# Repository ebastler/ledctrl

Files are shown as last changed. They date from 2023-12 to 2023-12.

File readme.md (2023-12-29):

# ledctrl
This project was born with the idea of creating a simple and efficient way of controlling an RGB, one WW/CW and an additional aux stripe from a single smart-home capable controller. Then feature creep happened, and here we are.

The PCB uses a modern and power-efficient RISC-V based ESP32C6 and features a step-down converter to supply the 5V logic, as well as an LDO for the 3.3V logic. The Aux channel has a separate supply input from the other 5 channels, and both supply domains can be used for 12V or 24V stripes, not necessarily the same voltage at the same time. The logic supply is generated from either of the two supply channels, which are ORed together with diodes.

2 inputs for external buttons can be used to directly control the LEDs, or send commands via MQTT. I also added headers for the most common breakout boards for a bunch of different environmental sensors. 

While programming over USB works without issues for ESP32C6, I also added a UART header as a fallback, for debugging or just for use as another GPIO breakout.

### Features:
* Up to 5+1 channels of 12V or 24V LED stripes
* ESP32C6
* USB-C for programming
* Dim onboard LEDs to indicate status of each PWM channel, as well as both input power domains
* WS2812B LED onboard as a status indicator/for devboard use
* Almost all unused GPIOs are available on headers
* Headers for BME280, SCD40 and SGP40 environment sensors
* 2 inputs for pushbuttons/switches

### Software
The board is mainly made for use with [Tasmota](https://github.com/arendst/tasmota), and currently only supported using the `tasmota32c6cdc` firmware, taken off the `13.3.0.1` development branch. Stable versions have not yet added support for this chip. A template that can make use of most features will be published at a later point, once I finalized my firmware setup.

### Pictures
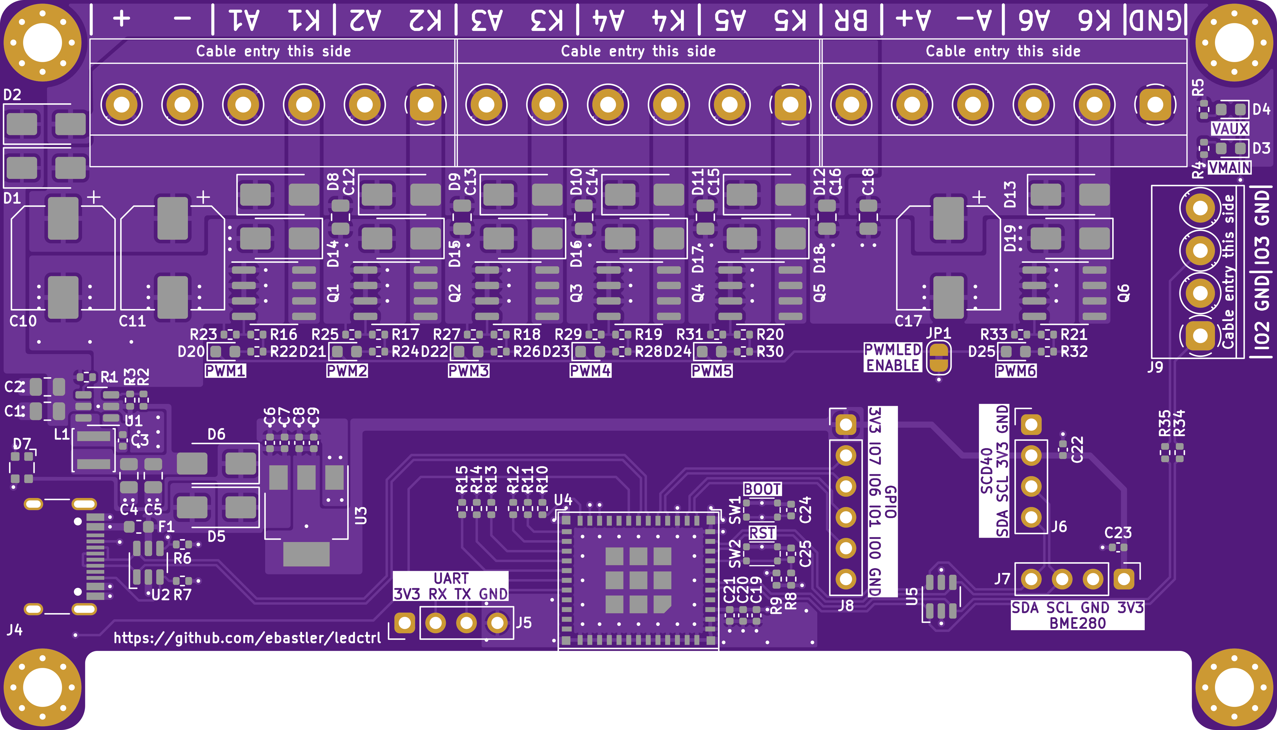
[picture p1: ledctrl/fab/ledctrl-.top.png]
topside


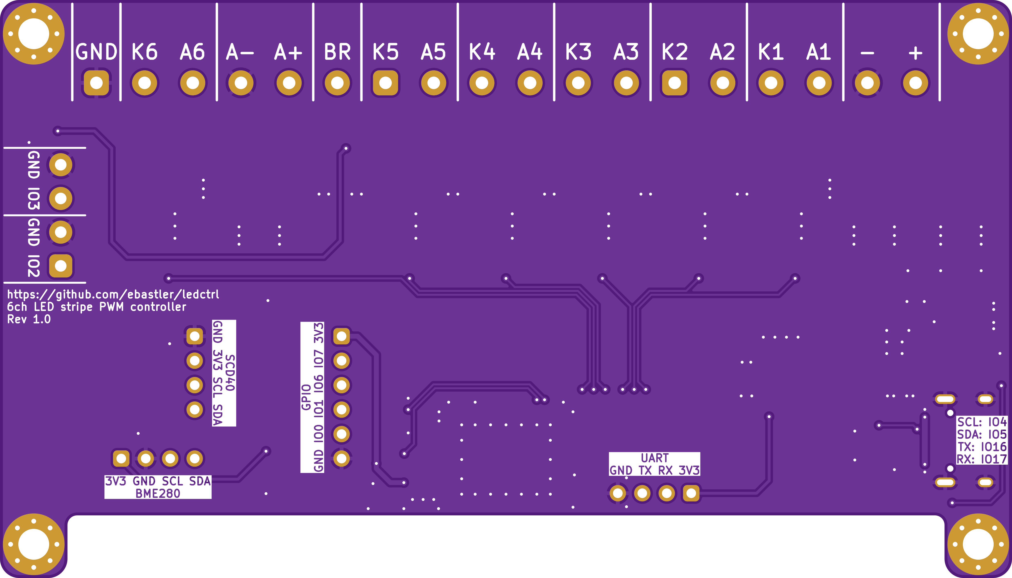
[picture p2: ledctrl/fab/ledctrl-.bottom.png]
botside


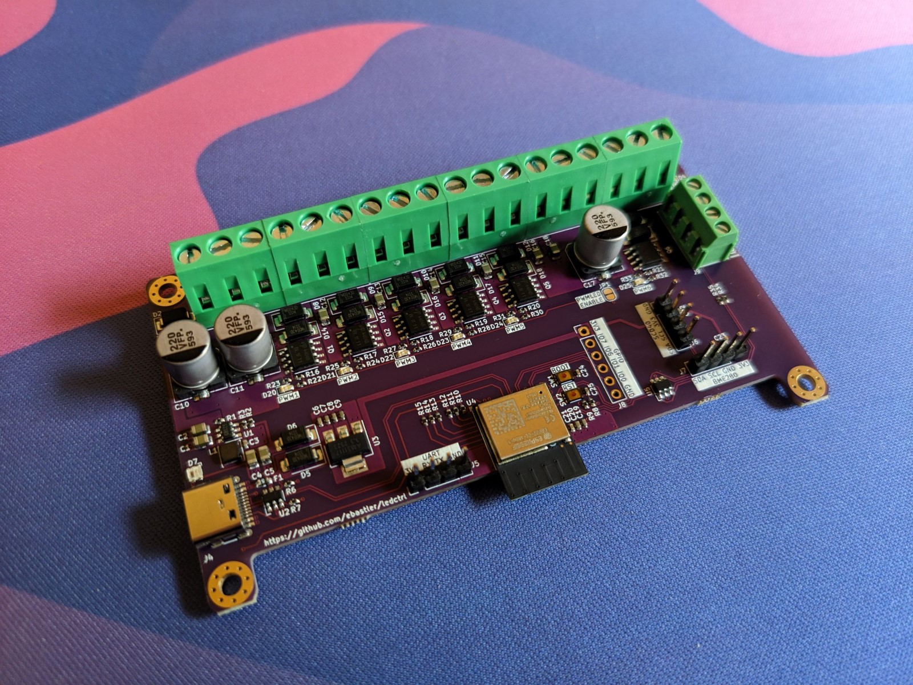
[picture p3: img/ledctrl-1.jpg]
overview of a PCB


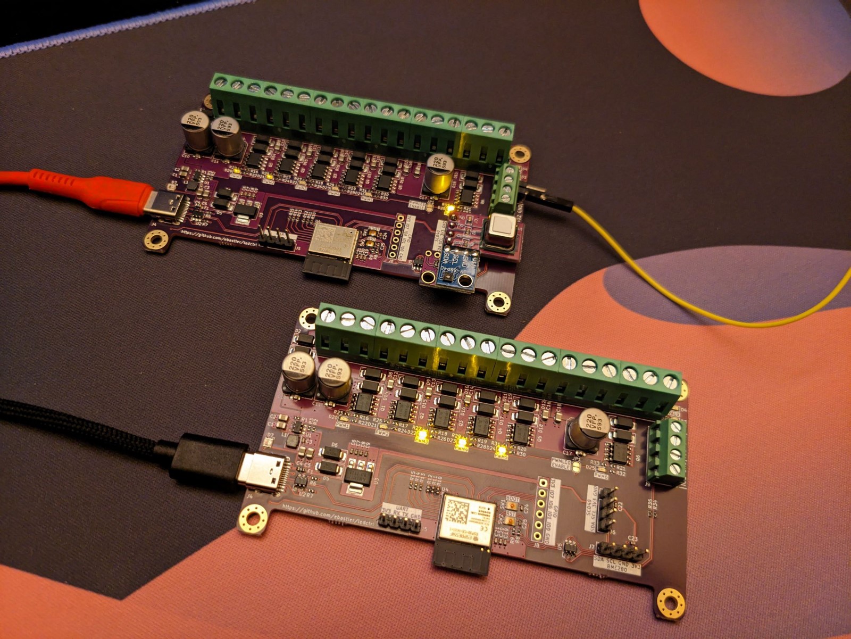
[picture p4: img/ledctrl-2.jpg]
PCBs being tested on a desk


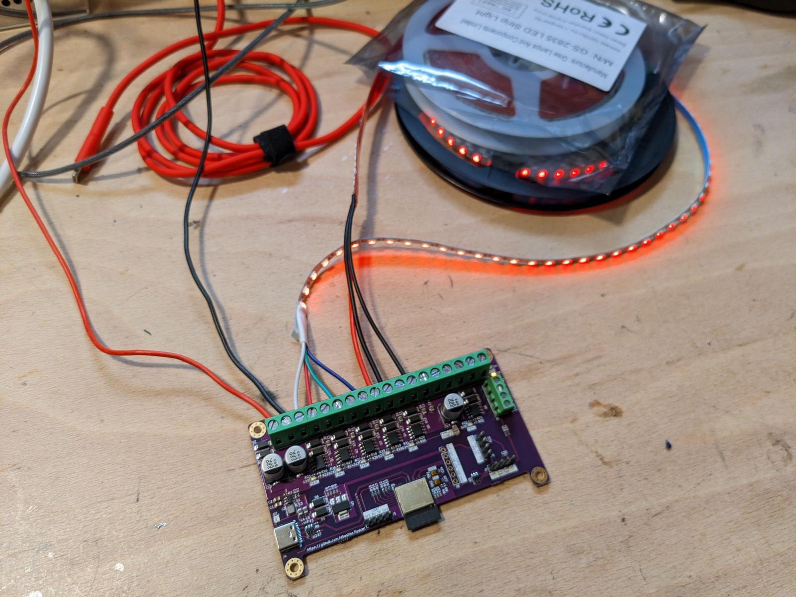
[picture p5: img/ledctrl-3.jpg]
PCB with active LED output


## Thanks
* arendst and the whole community of Tasmota contributors for their excellent firmware
* [MarvFPV](https://github.com/marvfpv) who surprisingly did not get upset about me sending updates of new revisions with minimal changes every other day asking for his opinion

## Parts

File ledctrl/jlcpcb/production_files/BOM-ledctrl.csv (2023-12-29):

Comment | Designator | Footprint | LCSC
BOOT | SW1,SW2 | SW_T1A2QR | C100056
AO4404B | Q1,Q2,Q3,Q4,Q5,Q6 | SOIC-8_3.9x4.9mm_P1.27mm | C115829
HRO M-12 | J4 | USB_C_Receptacle_HRO_TYPE-C-31-M-12 | C165948
0R | R10,R11,R12,R13,R14,R15,R34,R35 | R_0402_1005Metric | C17168
ST1 | J1,J2,J3 | TerminalBlock_Ningbo_Kangnex _WJ128V-5.0-6P_1x06_P5.00mm_Horizontal | C192771
500 mA | F1 | Fuse_0603_1608Metric | C20789
4u7 | C19,C20,C22,C23,C6,C7,C8,C9 | C_0402_1005Metric | C23733
SS14 | D1,D10,D11,D12,D13,D14,D15,D16,D17,D18,D19,D2,D5,D6,D8,D9 | D_SMA | C2480
100 | R16,R17,R18,R19,R20,R21 | R_0402_1005Metric | C25076
10k | R1,R23,R25,R27,R29,R3,R31,R33,R8 | R_0402_1005Metric | C25744
51k | R2,R4,R5 | R_0402_1005Metric | C25794
3k3 | R22,R24,R26,R28,R30,R32,R9 | R_0402_1005Metric | C25890
5k1 | R6,R7 | R_0402_1005Metric | C25905
UART | J5,J6,J7 | PinHeader_1x04_P2.54mm_Vertical | C2691448
EXP2 | J9 | TerminalBlock_DIBO_DB125-3.5-4P-GN-S_1x04_P3.50mm_Horizontal | C2757925
220u | C10,C11,C17 | CP_Elec_8x10 | C278406
TPMP2359DJ | U1 | SOT-23-6 | C2959845
100n | C21,C24,C3 | C_0402_1005Metric | C307331
4u7 | L1 | L_Changjiang_FNR3012S | C528014
1u | C25 | C_0402_1005Metric | C52923
ESP32-C6-MINI-1/U | U4 | ESP32-C6-MINI-1 | C5736265
22u | C1,C12,C13,C14,C15,C16,C18,C2,C4,C5 | C_0805_2012Metric | C6119901
AMS1117-3.3 | U3 | SOT-223-3_TabPin2 | C6186
Y | D20,D21,D22,D23,D24,D25,D3,D4 | LED_0603_1608Metric | C72038
SRV05-4 | U2,U5 | SOT-23-6-routable | C85364
WS2812 | D7 | LED_WS2812_2020 | C965555

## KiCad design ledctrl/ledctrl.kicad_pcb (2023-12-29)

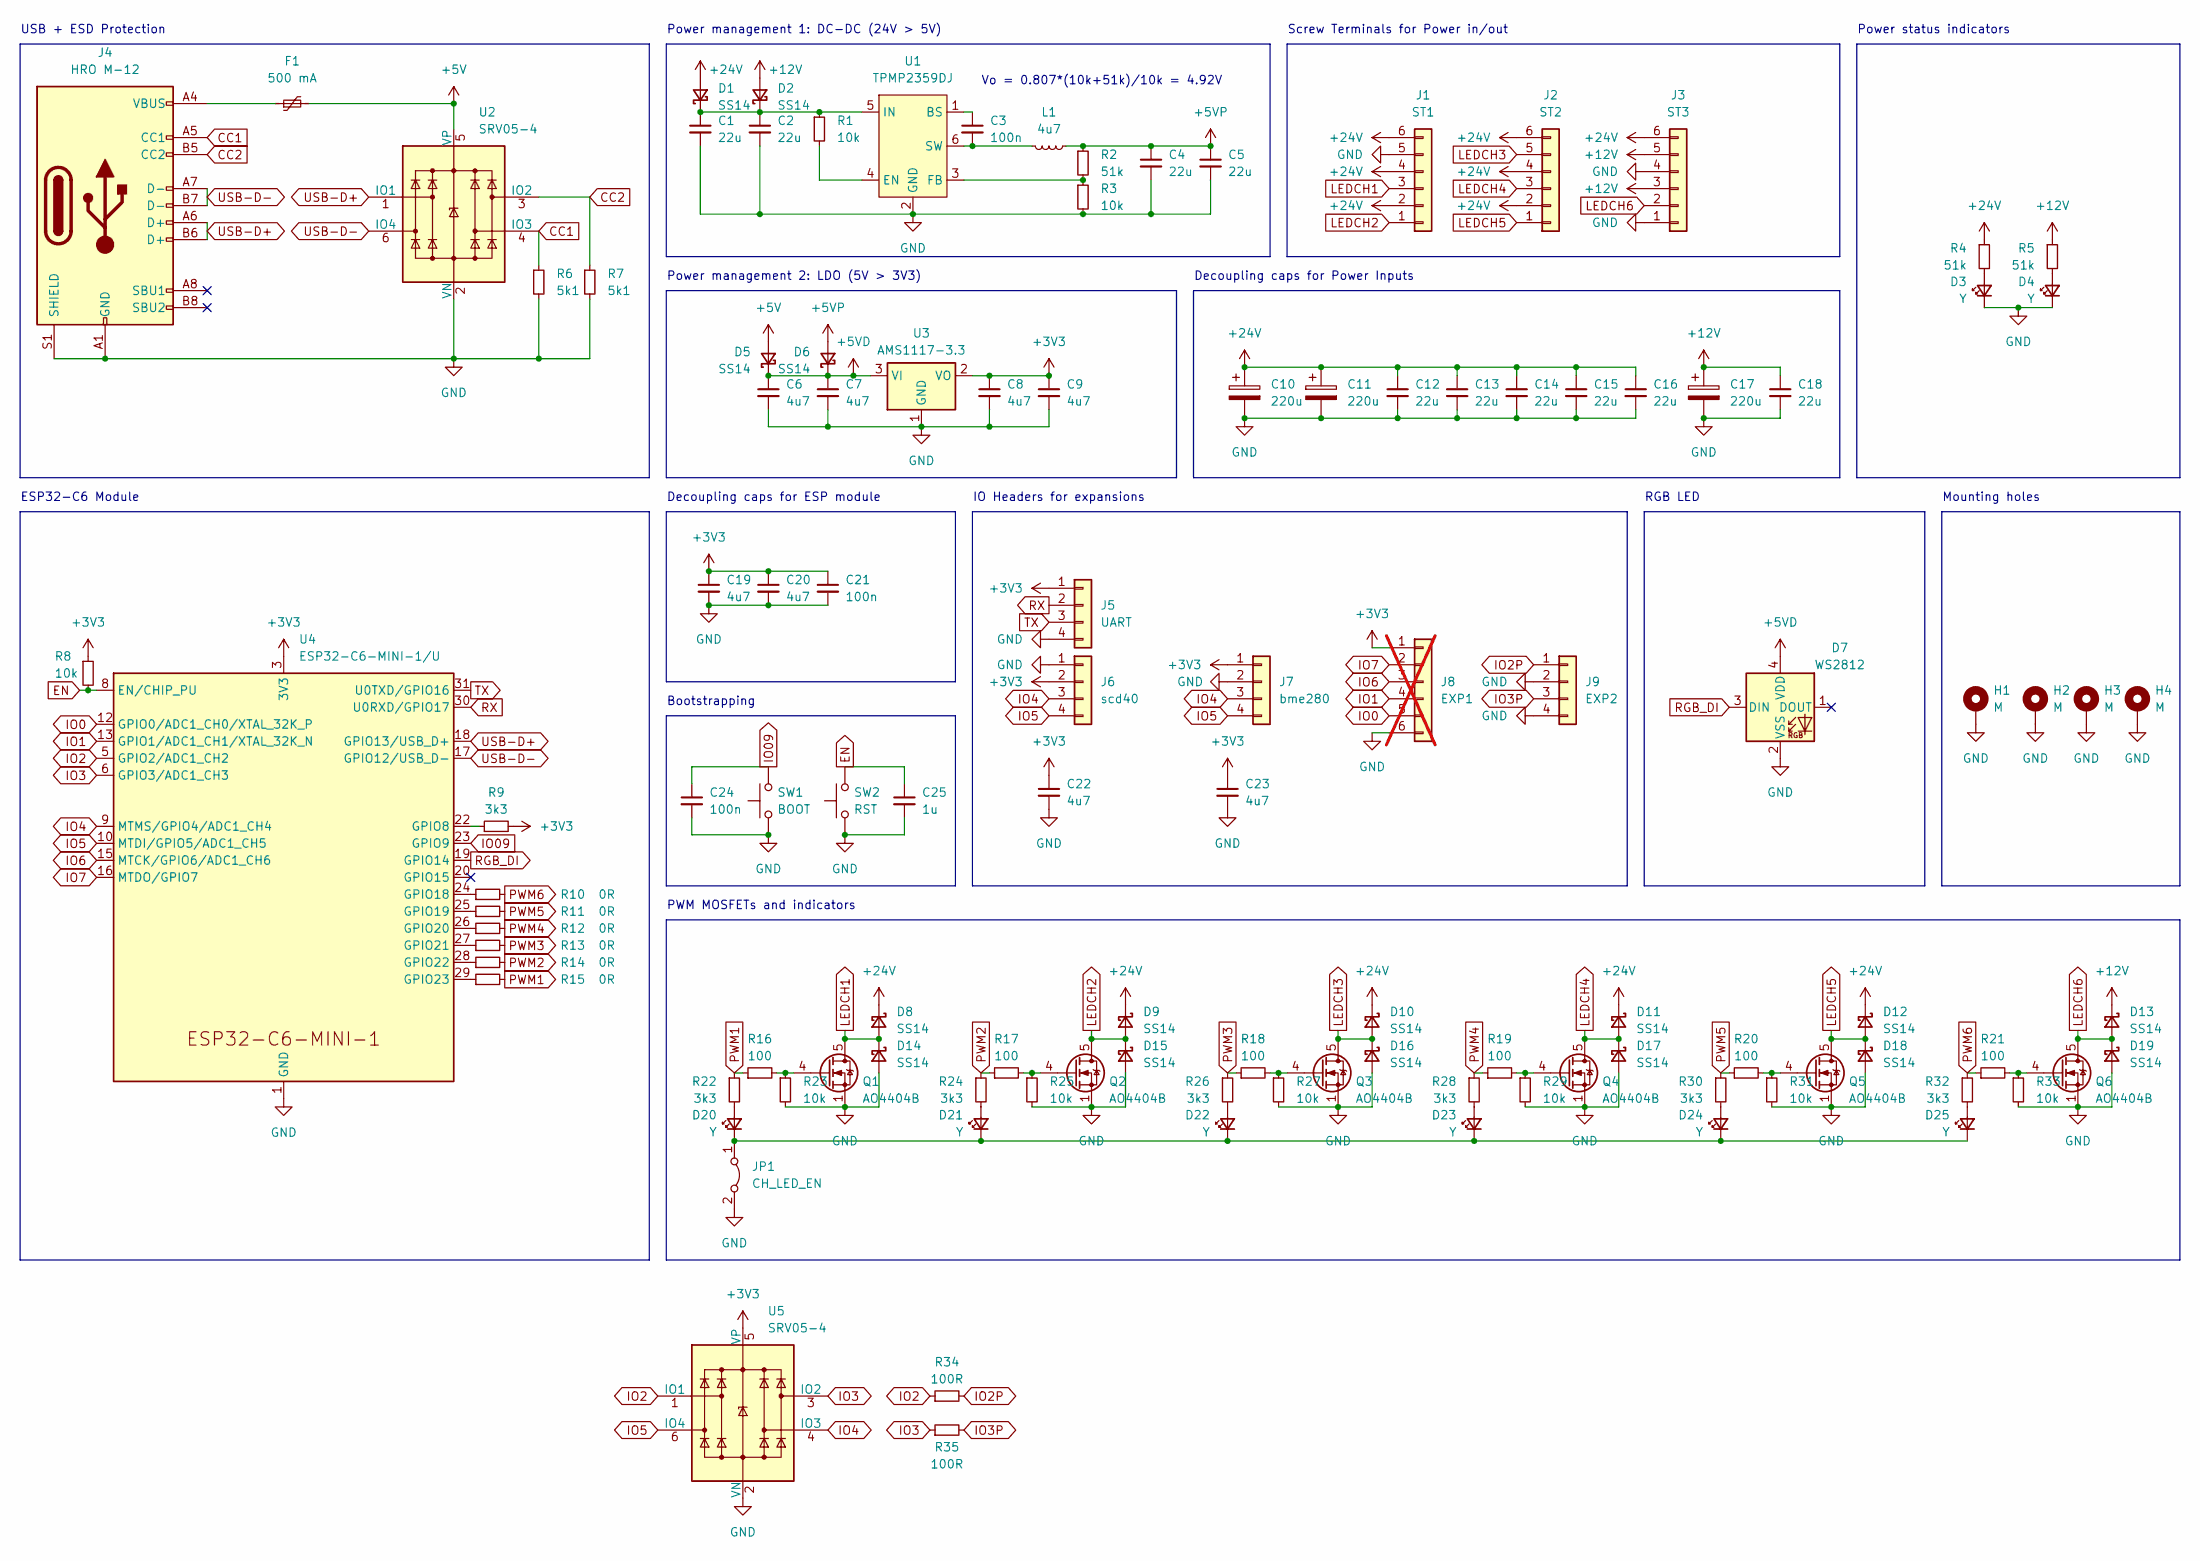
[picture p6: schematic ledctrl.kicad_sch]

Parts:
C1, C2, C4, C5, C12, C13, C14, C15, C16, C18: 22u; C_0805_2012Metric; LCSC C6119901
C3, C21, C24: 100n; C_0402_1005Metric
C6, C7, C8, C9, C19, C20, C22, C23: 4u7; C_0402_1005Metric
C10, C11, C17: 220u; CP_Elec_8x10; LCSC C278406
C25: 1u; C_0402_1005Metric
D1, D2, D5, D6, D8, D9, D10, D11, D12, D13, D14, D15, D16, D17, D18, D19: SS14; D_SMA
D3, D4, D20, D21, D22, D23, D24, D25: Y; LED_0603_1608Metric; LCSC C72038
D7: WS2812; LED_WS2812_2020
F1: 500 mA; Fuse_0603_1608Metric
H1, H2, H3, H4: M; MountingHole_3.2mm_M3_Pad_Via
J1: ST1; TerminalBlock_Ningbo_Kangnex _WJ128V-5.0-6P_1x06_P5.00mm_Ho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; LCSC C192771
J2: ST2; TerminalBlock_Ningbo_Kangnex _WJ128V-5.0-6P_1x06_P5.00mm_Ho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; LCSC C192771
J3: ST3; TerminalBlock_Ningbo_Kangnex _WJ128V-5.0-6P_1x06_P5.00mm_Ho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; LCSC C192771
J4: HRO M-12; USB_C_Receptacle_HRO_TYPE-C-31-M-12
J5: UART; PinHeader_1x04_P2.54mm_Vertical
J6: scd40; PinHeader_1x04_P2.54mm_Vertical
J7: bme280; PinHeader_1x04_P2.54mm_Vertical
J8: EXP1; PinHeader_1x06_P2.54mm_Vertical; not fitted
J9: EXP2; TerminalBlock_DIBO_DB125-3.5-4P-GN-S_1x04_P3.50mm_Horizontal; LCSC C2757925
JP1: CH_LED_EN; SolderJumper-2_P1.3mm_Bridged_RoundedPad1.0x1.5mm
L1: 4u7; L_Changjiang_FNR3012S; LCSC C528014
Q1, Q2, Q3, Q4, Q5, Q6: AO4404B; SOIC-8_3.9x4.9mm_P1.27mm
R1, R3, R8, R23, R25, R27, R29, R31, R33: 10k; R_0402_1005Metric
R2, R4, R5: 51k; R_0402_1005Metric
R6, R7: 5k1; R_0402_1005Metric
R9, R22, R24, R26, R28, R30, R32: 3k3; R_0402_1005Metric
R10, R11, R12, R13, R14, R15: 0R; R_0402_1005Metric; LCSC C17168
R16, R17, R18, R19, R20, R21: 100; R_0402_1005Metric
R34, R35: 100R; R_0402_1005Metric; LCSC C17168
SW1: BOOT; SW_T1A2QR
SW2: RST; SW_T1A2QR
U1: TPMP2359DJ; SOT-23-6
U2, U5: SRV05-4; SOT-23-6-routable
U3: AMS1117-3.3; SOT-223-3_TabPin2
U4: ESP32-C6-MINI-1/U; ESP32-C6-MINI-1

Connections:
+3V3: C8.1, C9.1, C19.1, C20.1, C21.1, C22.1, C23.1, J5.1, J6.2, J7.1, J8.1, R8.1, R9.2, U3.2 (VO), U4.3 (3V3), U5.5 (VP)
+5V: D5.2 (A), F1.2, U2.5 (VP)
+5VD: C6.1, C7.1, D5.1 (K), D6.1 (K), D7.4 (VDD), U3.3 (VI)
+5VP: C4.1, C5.1, D6.2 (A), L1.1, R2.1
+12V: C17.1, C18.1, D2.2 (A), D13.1 (K), J3.3, J3.5, R5.1
+24V: C10.1, C11.1, C12.1, C13.1, C14.1, C15.1, C16.1, D1.2 (A), D8.1 (K), D9.1 (K), D10.1 (K), D11.1 (K), D12.1 (K), J1.2, J1.4, J1.6, J2.2, J2.4, J2.6, J3.6, R4.1
CC1: J4.A5 (CC1), R6.1, U2.4 (IO3)
CC2: J4.B5 (CC2), R7.1, U2.3 (IO2)
EN: C25.1, R8.2, SW2.2, U4.8 (EN/CHIP_PU)
GND: C1.2, C2.2, C4.2, C5.2, C6.2, C7.2, C8.2, C9.2, C10.2, C11.2, C12.2, C13.2, C14.2, C15.2, C16.2, C17.2, C18.2, C19.2, C20.2, C21.2, C22.2, C23.2, C24.2, C25.2, D3.1 (K), D4.1 (K), D7.2 (VSS), D14.2 (A), D15.2 (A), D16.2 (A), D17.2 (A), D18.2 (A), D19.2 (A), H1.1, H2.1, H3.1, H4.1, J1.5, J3.1, J3.4, J4.A1 (GND), J4.A12 (GND), J4.B1 (GND), J4.B12 (GND), J4.S1 (SHIELD), J5.4, J6.1, J7.2, J8.6, J9.2, J9.4, JP1.2 (B), Q1.1 (S), Q1.2 (S), Q1.3 (S), Q2.1 (S), Q2.2 (S), Q2.3 (S), Q3.1 (S), Q3.2 (S), Q3.3 (S), Q4.1 (S), Q4.2 (S), Q4.3 (S), Q5.1 (S), Q5.2 (S), Q5.3 (S), Q6.1 (S), Q6.2 (S), Q6.3 (S), R3.2, R6.2, R7.2, R23.2, R25.2, R27.2, R29.2, R31.2, R33.2, SW1.1, SW2.1, U1.2 (GND), U2.2 (VN), U3.1 (GND), U4.1 (GND), U4.2 (GND), U4.11 (GND), U4.14 (GND), U4.36 (GND), U4.37 (GND), U4.38 (GND), U4.39 (GND), U4.40 (GND), U4.41 (GND), U4.42 (GND), U4.43 (GND), U4.44 (GND), U4.45 (GND), U4.46 (GND), U4.47 (GND), U4.48 (GND), U4.49 (GND), U4.50 (GND), U4.51 (GND), U4.52 (GND), U4.53 (GND), U5.2 (VN)
IO0: J8.5, U4.12 (GPIO0/ADC1_CH0/XTAL_32K_P)
IO1: J8.4, U4.13 (GPIO1/ADC1_CH1/XTAL_32K_N)
IO2: R34.1, U4.5 (GPIO2/ADC1_CH2), U5.1 (IO1)
IO2P: J9.1, R34.2
IO3: R35.1, U4.6 (GPIO3/ADC1_CH3), U5.3 (IO2)
IO3P: J9.3, R35.2
IO4: J6.3, J7.3, U4.9 (MTMS/GPIO4/ADC1_CH4), U5.4 (IO3)
IO5: J6.4, J7.4, U4.10 (MTDI/GPIO5/ADC1_CH5), U5.6 (IO4)
IO6: J8.3, U4.15 (MTCK/GPIO6/ADC1_CH6)
IO7: J8.2, U4.16 (MTDO/GPIO7)
IO09: C24.1, SW1.2, U4.23 (GPIO9)
LEDCH1: D8.2 (A), D14.1 (K), J1.3, Q1.5 (D), Q1.6 (D), Q1.7 (D), Q1.8 (D)
LEDCH2: D9.2 (A), D15.1 (K), J1.1, Q2.5 (D), Q2.6 (D), Q2.7 (D), Q2.8 (D)
LEDCH3: D10.2 (A), D16.1 (K), J2.5, Q3.5 (D), Q3.6 (D), Q3.7 (D), Q3.8 (D)
LEDCH4: D11.2 (A), D17.1 (K), J2.3, Q4.5 (D), Q4.6 (D), Q4.7 (D), Q4.8 (D)
LEDCH5: D12.2 (A), D18.1 (K), J2.1, Q5.5 (D), Q5.6 (D), Q5.7 (D), Q5.8 (D)
LEDCH6: D13.2 (A), D19.1 (K), J3.2, Q6.5 (D), Q6.6 (D), Q6.7 (D), Q6.8 (D)
unnamed: C1.1, C2.1, D1.1 (K), D2.1 (K), R1.1, U1.5 (IN)
unnamed: D3.2 (A), R4.2
unnamed: D4.2 (A), R5.2
unnamed: D20.2 (A), R22.2
unnamed: D20.1 (K), D21.1 (K), D22.1 (K), D23.1 (K), D24.1 (K), D25.1 (K), JP1.1 (A)
unnamed: D21.2 (A), R24.2
unnamed: D22.2 (A), R26.2
unnamed: D23.2 (A), R28.2
unnamed: D24.2 (A), R30.2
unnamed: D25.2 (A), R32.2
unnamed: F1.1, J4.A4 (VBUS), J4.A9 (VBUS), J4.B4 (VBUS), J4.B9 (VBUS)
unnamed: Q1.4 (G), R16.2, R23.1
unnamed: Q2.4 (G), R17.2, R25.1
unnamed: Q3.4 (G), R18.2, R27.1
unnamed: Q4.4 (G), R19.2, R29.1
unnamed: Q5.4 (G), R20.2, R31.1
unnamed: Q6.4 (G), R21.2, R33.1
unnamed: C3.1, U1.1 (BS)
unnamed: R1.2, U1.4 (EN)
unnamed: R2.2, R3.1, U1.3 (FB)
unnamed: C3.2, L1.2, U1.6 (SW)
unnamed: R9.1, U4.22 (GPIO8)
unnamed: R10.1, U4.24 (GPIO18)
unnamed: R11.1, U4.25 (GPIO19)
unnamed: R12.1, U4.26 (GPIO20)
unnamed: R13.1, U4.27 (GPIO21)
unnamed: R14.1, U4.28 (GPIO22)
unnamed: R15.1, U4.29 (GPIO23)
PWM1: R15.2, R16.1, R22.1
PWM2: R14.2, R17.1, R24.1
PWM3: R13.2, R18.1, R26.1
PWM4: R12.2, R19.1, R28.1
PWM5: R11.2, R20.1, R30.1
PWM6: R10.2, R21.1, R32.1
RGB_DI: D7.3 (DIN), U4.19 (GPIO14)
RX: J5.2, U4.30 (U0RXD/GPIO17)
TX: J5.3, U4.31 (U0TXD/GPIO16)
USB-D+: J4.A6 (D+), J4.B6 (D+), U2.1 (IO1), U4.18 (GPIO13/USB_D+)
USB-D-: J4.A7 (D-), J4.B7 (D-), U2.6 (IO4), U4.17 (GPIO12/USB_D-)

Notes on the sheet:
IO Headers for expansions
Vo = 0.807*(10k+51k)/10k = 4.92V
Bootstrapping
Power management 2: LDO (5V > 3V3)
Screw Terminals for Power in/out
Mounting holes
Power management 1: DC-DC (24V > 5V)
USB + ESD Protection
Decoupling caps for ESP module
ESP32-C6 Module
Decoupling caps for Power Inputs
Power status indicators
RGB LED
PWM MOSFETs and indicators

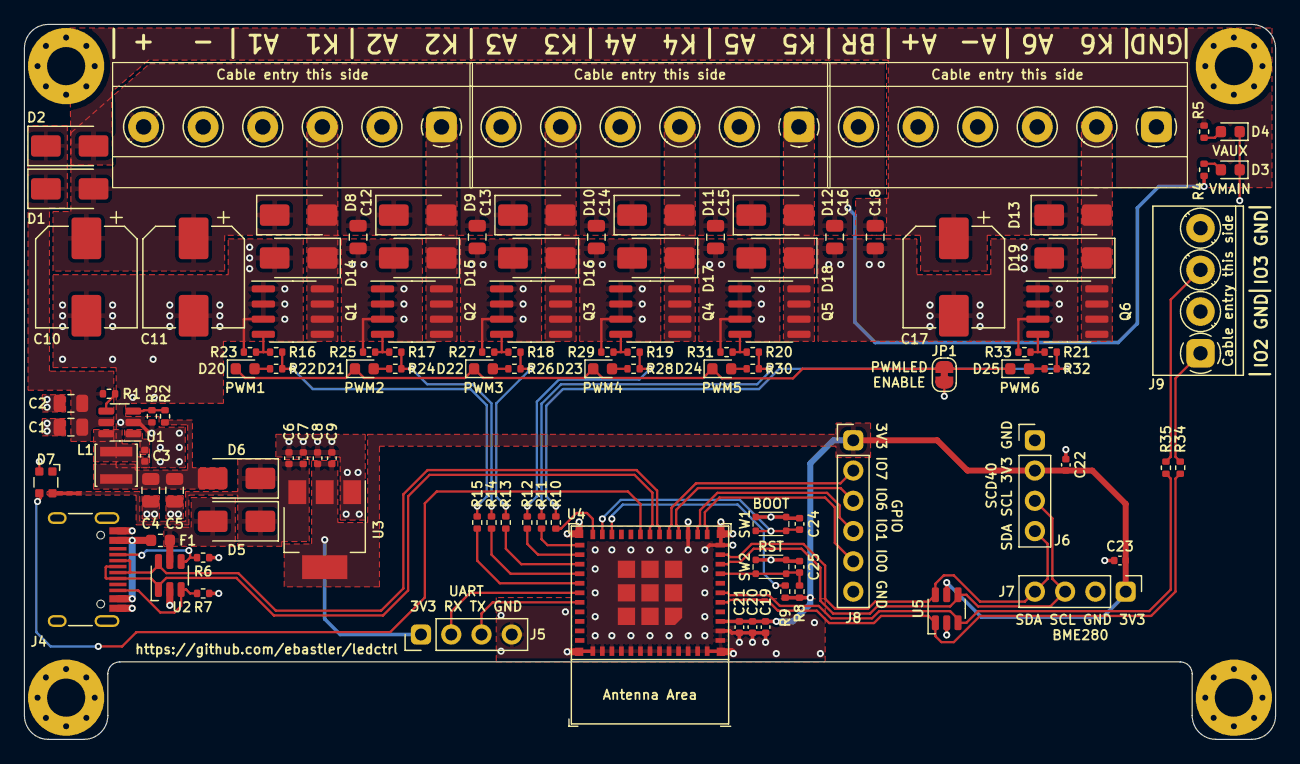
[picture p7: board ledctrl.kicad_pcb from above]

Board: 2 copper layers, 105.0 x 60.0 mm, 114 parts (0 on the bottom side), 66 nets.

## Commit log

2023-12-29 removed .csv from gitignore for BOM/POS files
2023-12-29 initial commit of kicad project files
    [BOM-ledctrl.csv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]
